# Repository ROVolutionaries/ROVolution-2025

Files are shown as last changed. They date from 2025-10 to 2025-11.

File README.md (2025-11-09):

# ROVolution 2025 Open-Sourced Resources

## **Table of Contents**

* [Hardware](./Hardware) — PCB designs for the ROV’s Power Distribution and Control Boards, created in KiCad with accompanying schematics, layouts, and 3D models.
* [Software](./Software) — Python and C++ code for ROV control, communication, and image processing, including surface interfaces, Raspberry Pi and Pico firmware, and testing utilities.
* [Model](./Model) — 3D models, renders, and Fusion 360 assemblies of the ROV components
* [Ocean Exploration Video Challenge](./Ocean%20Exploration%20Video%20Challenge) — Object detection and classification of ocean species for the NOAA Ocean Exploration Video Challenge. 

---

## **Contributions and Disclaimers**

This repository represents a portion of the overall ROVolution 2025 project, focusing primarily on **design, software development, and task-specific coding**. It does **not include full ROVolutionaries work**. This repository only highlights the contributions specifically carried out by the following members:

* **Konstantin Logashenko (CEO)** — PCB design and software.
* **Dewei David Zhang (CTO)** — CAD design and code contributions.
* **Muhammad Ahmed Shaikh (former CEO)** — software and code contributions.

---

## **More on ROVolution**

* [YouTube](https://www.youtube.com/@ROVolutionaries)
* [Instagram](https://www.instagram.com/rovolutionaries/)
* [Technical Documentation](https://drive.google.com/file/d/1zGqDDCye5YSRfjU_IAGbzJyzfevygd78/view?usp=sharing)
* [Additional Files](https://docs.google.com/spreadsheets/d/10eZ-Em9sXnn5XWBDeCyZJDLGmav5vlog2l0rmnmTBGw/edit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)

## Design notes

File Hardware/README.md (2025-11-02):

# Hardware

---

## **Power Distribution Board (PDB)**

Power Distribution Board
*Note: a few XT60 connectors were not attached in this image.*

**Download:**

* [PDB schematic (`.kicad_sch`)](Power_Distribution_Board/PDB.kicad_sch)
* [PDB PCB layout (`.kicad_pcb`)](Power_Distribution_Board/PDB.kicad_pcb)
* [PDB 3D model (`.step`)](Power_Distribution_Board/PDB.step)
* [PDB bill of materials (`.csv`)](Power_Distribution_Board/PDB.csv)
* [PDB XML export (`.xml`)](Power_Distribution_Board/PDB.xml)
* [PDB project file (`.kicad_pro`)](Power_Distribution_Board/PDB.kicad_pro)
* [PDB KiCad backup schematic (`.kicad_sch-bak`)](Power_Distribution_Board/PDB.kicad_sch-bak)
* [PDB KiCad project local file (`.kicad_prl`)](Power_Distribution_Board/PDB.kicad_prl)

---

## **Control Board**

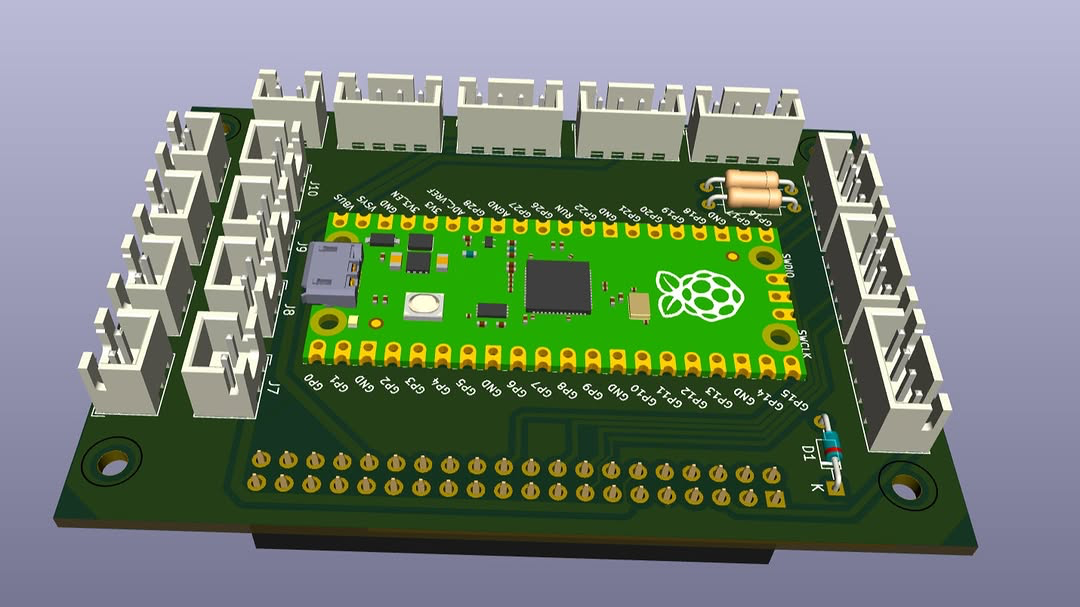
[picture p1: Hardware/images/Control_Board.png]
Control Board


**Download:**

* [Control Board schematic (`.kicad_sch`)](Control_Board/Control_Board.kicad_sch)
* [Control Board PCB layout (`.kicad_pcb`)](Control_Board/Control_Board.kicad_pcb)
* [Control Board 3D model (`.step`)](Control_Board/Control_Board.step)
* [Control Board project file (`.kicad_pro`)](Control_Board/Control_Board.kicad_pro)
* [Control Board KiCad backup schematic (`.kicad_sch-bak`)](Control_Board/Control_Board.kicad_sch-bak)
* [Control Board KiCad project local file (`.kicad_prl`)](Control_Board/Control_Board.kicad_prl)
* [Control Board legacy project file (`.pro`)](Control_Board/Control_Board.pro)

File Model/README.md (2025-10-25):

# Models

---

## **ROV Model**

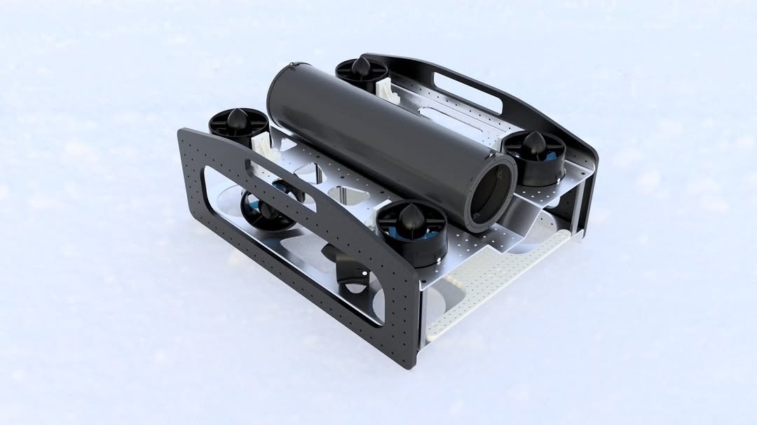
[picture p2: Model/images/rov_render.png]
ROV CAD render

ROV image
[Pool Test Video](https://youtu.be/HalhtXvYYro)

**Download:**  
- [ROV STEP file](files/ROV.step) ([f3z Google Drive file](https://drive.google.com/file/d/1CSuDAXggwamgUQ0F3YDBGZ4MGBTvEjoI/view?usp=sharing))
- [Gripper STEP file](files/Gripper.step) ([f3z Google Drive file](https://drive.google.com/file/d/1I8YvQWp7bbg3L94b0wb-usT_5LE429A_/view?usp=sharing))
- [Photosphere Github download](files/Photosphere.step) ([f3z file](files/Photosphere.f3z))

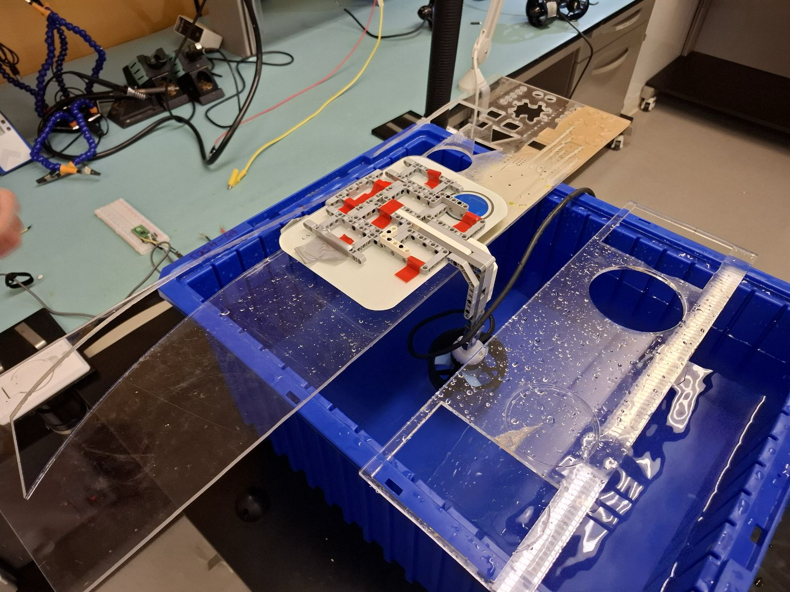
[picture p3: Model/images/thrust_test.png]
Thrust test setup


A custom T200-to-Lego adapter was designed for thrust testing. The STL file can be accessed [here](files/T200_Lego.stl). 

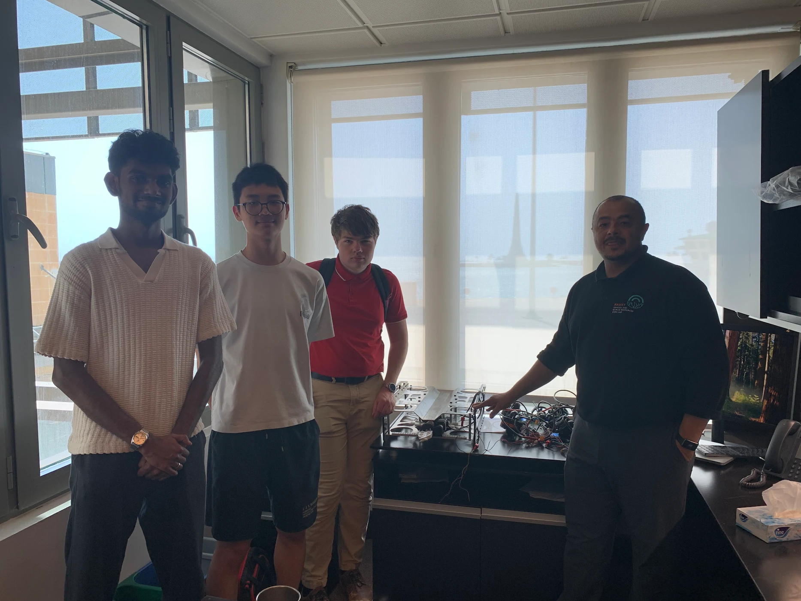
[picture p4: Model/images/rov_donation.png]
ROV donation


After the competition, a representative from the Coastal and Marine Resources Core Lab (CMR), one of our sponsors, was impressed by our design of the ROV. As a gesture of appreciation for CMR’s support, we decided to donate the ROV to CMR for their professional applications.

---

## **Float Model**

Float

**Download:**  

- [Float STEP file](files/Float.step) ([f3z file](files/Float.f3z))

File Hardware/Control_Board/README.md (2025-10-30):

Created in KiCAD 8.0 <br>
Control board of the ROV, follows the Raspberry Pi HAT specification for size, connects to the GPIO pins (does not include EEPROM for identification as per the official spec.
Raspberry Pi is backpowered through the HAT, not ideal however since not all supply protection was included. <br>
All connectors are JST8

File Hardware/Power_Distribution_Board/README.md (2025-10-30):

Project created in KiCAD 8.0
PCB for distributing 12V and 5V power to other component
12 V XT60 Connectors for 8 ESCs, 2 for auxillary components
5V JST8 Connector
Parallel capacitance added on 12 V tether line to balance out tether inductance, reducing voltage spikes due to changes in current drad
TVS diode to protect if transient voltage spikes do occur as described above

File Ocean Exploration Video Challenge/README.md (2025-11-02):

# Program Explanation

**NOAA Ocean Exploration**  
**Ocean Exploration Video Challenge**

---

## **Compute Resources**

Training a visual detection model is computationally intensive, especially when using a dataset of 99k images, as we did. Most laptop and desktop computers will struggle with upwards of 100 images when training on CPUs, and training with one GPU introduces unreasonable training times for large datasets. Therefore, we decided to use a GPU cluster provided by AWS. There, we stored all of our images and trained using job scripts in the SLURM format.  

For prototyping and proof-of-concept purposes, we began by training in Google Colab, but were limited by free GPU credits. Then, we used an AWS cluster with one GPU. Finally, we trained our model using 8 GPUs in the AWS cluster.  

---

## **Code Overview**

We decided to use the model architecture **YOLOv9** with pretrained weights to train our model. Let’s go step by step and learn how to code the model (*please note that most code blocks are snippets and not fully executable scripts*).  

### **Fetching the Data**

This step involves downloading the provided JSON file from **FathomNet**, which contains references to various locations for bounding box annotations, file names, and classes. To maintain consistency, we named each image with its UUID. Below is a snippet of the function we used for this purpose:

```python
def download_image(file):
    filename = file["uuid"]
    url = file["url"]
    image_path = os.path.join(images_directory, filename + ".png")

    if not os.path.exists(image_path):
        try:
            response = requests.get(url, timeout=10)
            if response.status_code == 200:
                with open(image_path, "wb") as img_file:
                    img_file.write(response.content)
                print(f"Image {filename} downloaded successfully.")
                return True
            else:
                print(f"Failed to retrieve the image {filename}. Status code: {response.status_code}")
                return False
        except requests.RequestException as e:
            print(f"Error downloading {filename}: {e}")
            return False
    else:
        print(f"Image {filename} already exists. Skipping download.")
        return False
````

To increase the efficiency of downloading the images, we applied concurrent downloads as shown below:

```python
with ThreadPoolExecutor(max_workers=50) as executor:
    futures = [executor.submit(download_image, file) for file in data]
    for future in as_completed(futures):
        future.result()
```

---

### **Refining the Data**

During the organisation of the files, we refined the dataset to remove any files without crucial information for training purposes and any images or JSON entries that didn’t match or were extra. For example, here is a code snippet to find any extra JSON entries or extra image files:

```python
json_file_path = "data.json"
images_directory = "images/"

with open(json_file_path, "r") as file:
    data = json.load(file)

json_filenames = {entry["uuid"] + ".png" for entry in data}
image_filenames = {filename for filename in os.listdir(images_directory) if filename.endswith(".png")}

extra_json_entries = json_filenames - image_filenames
extra_image_files = image_filenames - json_filenames
```

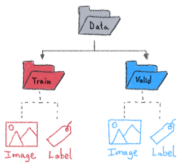
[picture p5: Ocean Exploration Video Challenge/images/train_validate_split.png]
Dataset refinement example


---

### **Organising in YOLO Format**

YOLOv9 requires a very specific data setup for it to function. The basic structure is:
`labels/` and `images/` directories, containing `train/` and `val/` subdirectories (often with an 80/20 split respectively), plus a `data.yaml` file outlining directory paths, number of classes, and class names.

To start, we will use the JSON file of the dataset (in our case FathomNet) to extract the annotations and classes with which we will create our YOLO dataset. Here is a snippet of the function we used to do this:

```python
def extract_json(filename):
    json_file_path = filename
    parser = []

    with open(json_file_path, "r") as file:
        data = json.load(file)  # A

    for file in data:
        filename = os.path.join(file["uuid"] + ".png")
        imgwidth = file["width"]
        imgheight = file["height"]
        for box in file["boundingBoxes"]:
            name = box["concept"]
            boxx = box["x"]
            boxy = box["y"]
            boxwidth = box["width"]
            boxheight = box["height"]  # B
```

Section **A** loads the JSON file given the file path, and section **B** extracts all the necessary data from each JSON entry corresponding to an image.

We used these extracted values to create the `.txt` annotation files in the labels directory, as well as extracting class names later.

To construct the directories, we used the `os` module in Python, specifically `os.makedirs`:

```python
os.makedirs("/ALLFathomNET_images/images/train", exist_ok=True)  # A
os.makedirs("/ALLFathomNET_images/images/val", exist_ok=True)    # A
os.makedirs("/ALLFathomNET_images/labels/train", exist_ok=True)  # A
os.makedirs("/ALLFathomNET_images/labels/val", exist_ok=True)    # A

def save_data(filename, images_folder_path, labels_folder_path, group_obj):
    source = os.path.join("/ALLFathomNET_images/images", filename)
    destination = os.path.join(images_folder_path, filename)
    move(source, destination)
    text_filename = os.path.join(labels_folder_path, os.path.splitext(filename)[0] + ".txt")
    group_obj.get_group(filename).set_index("filename").to_csv(text_filename, sep=' ', index=False, header=False)  # B
```

In the code block above, we created the necessary directories with section **A** and loaded all the annotations and images into their respective directories with section **B**.

Finally, we made our `data.yaml` file containing the key pointers the model needs to access the data:

```python
data = {
    'train': '/ALLFathomNET_images/images/train',
    'val': '/ALLFathomNET_images/images/test',
    'nc': len(labels),
    'names': list(labels.keys())
}

with open('/ALLFathomNET_images/data.yaml', 'w') as file:
    yaml.dump(data, file, default_flow_style=False, sort_keys=False)
```

---

### **Training the Model**

Training with YOLOv9 consists of using the `train.py` function obtained from cloning the repository. In a kernel or terminal, run:

```bash
%cd {HOME}/yolov9  # A
!python train.py \
  --batch 16 --epochs 50 --img 640 --device 0 --min-items 0 --close-mosaic 15 \  # B
  --data /ALLFathomNET_images/data.yaml \  # C
  --weights {HOME}/weights/gelan-c.pt \    # D
  --cfg models/detect/gelan-c.yaml \       # E
  --hyp hyp.scratch-high.yaml
```

Section **A** navigates to the `yolov9` directory cloned from GitHub. Section **B** sets basic parameters for model training. Setting `device=0` means training on one GPU. Sections **C**, **D**, and **E** provide paths to the `data.yaml` file, weights file, and configuration file respectively.

We used the **gelan-c** variant due to its lower computational demands while maintaining strong performance.

---

### **Viewing the Results**

Once training is complete, a `results.png` file will appear showing key model performance metrics (loss and precision).

* **Loss** quantifies the disparity between predictions and true labels.
* **Precision** = True Positives / (True Positives + False Positives).

To view results:

```python
from IPython.display import Image
Image(filename=f"{HOME}/yolov9/runs/train/exp/results.png", width=1000)
```

You can also plot training progress directly using the `results.csv` file:

```python
import pandas as pd
import matplotlib.pyplot as plt

csv_files = [
    'path/to/results1.csv',
    'path/to/results2.csv',
    'path/to/results3.csv'  # A
]

combined_df = pd.DataFrame()
epoch_counter = 0

for csv_file in csv_files:
    df = pd.read_csv(csv_file)  # B
    df.index += epoch_counter
    combined_df = pd.concat([combined_df, df], ignore_index=True)
    epoch_counter += len(df)

plt.figure(figsize=(8, 6))  # C
plt.plot(combined_df.index, combined_df['train/box_loss'], label='Train Box Loss', color='blue')
plt.title('Train Box Loss Over Epochs')
plt.xlabel('Epoch')
plt.ylabel('Loss')
plt.legend()
plt.grid(True)
plt.show()
```

Section **A** defines paths to CSV files, **B** concatenates them, and **C** plots one of the metrics. There are 13 in total.

---

## **User Guide**

The YOLOv9 GitHub repository includes a Python file for running model inference.

To use the model for object detection in a video:

1. Download our trained model weights.
2. Clone the [YOLOv9 GitHub repository](https://github.com/WongKinYiu/yolov9).
3. Use a terminal window and navigate to that directory.
4. Run the following commands:

```bash
pip install -r requirements.txt
python detect.py --source /path/to/video.mp4 --weights '/path/to/weights.pt'
```

The output will indicate the directory where the processed video is saved.

---

## **Model Metrics**

Training metrics can be broadly split into **precision** and **loss**. Over time, performance plateaus even though training continues. By observing these graphs, we can identify when to stop training.

If training metrics improve while validation metrics plateau, the model is **overfitting**.

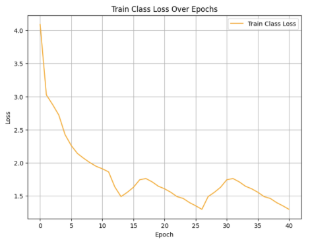
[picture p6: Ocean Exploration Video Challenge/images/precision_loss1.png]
Precision and Loss Plot 1

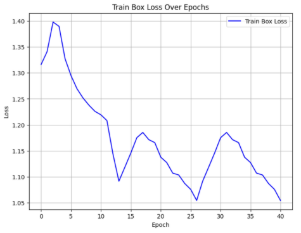
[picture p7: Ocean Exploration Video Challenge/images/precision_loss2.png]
Precision and Loss Plot 2


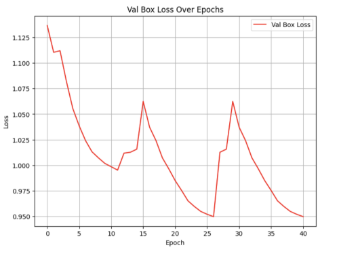
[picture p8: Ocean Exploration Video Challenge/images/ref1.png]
ref1

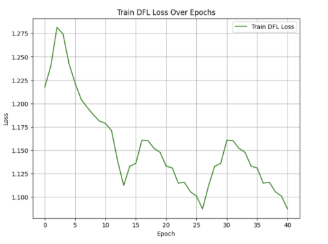
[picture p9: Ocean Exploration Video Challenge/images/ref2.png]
ref2


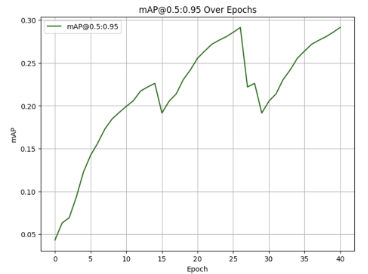
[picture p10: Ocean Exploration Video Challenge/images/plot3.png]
Plot 3

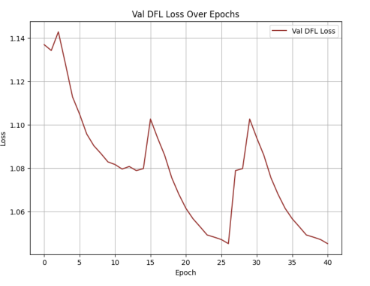
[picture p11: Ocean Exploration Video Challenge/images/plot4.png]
Plot 4

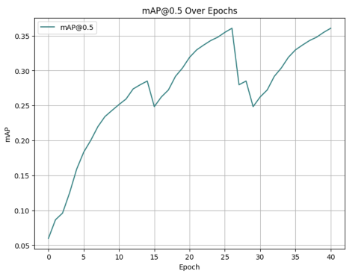
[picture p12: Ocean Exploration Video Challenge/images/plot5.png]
Plot 5

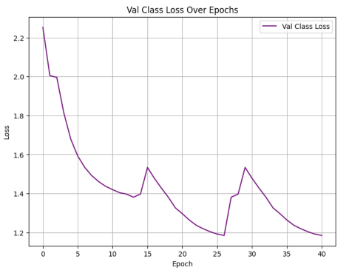
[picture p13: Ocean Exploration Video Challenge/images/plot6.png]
Plot 6


We can see that both the precision and loss metrics have plateaued, indicating that further training would show little improvement. However, large spikes in the middle of training suggest that an incorrect weights file may have been transferred between sessions, reducing model accuracy.

[ref1]: images/ref1.png
[ref2]: images/ref2.png

---

## Model Availability and Credits

Our final trained **YOLOv9 model** is publicly available under an open-source license for research and educational use.

**Download:**  
[Trained model weights (.pt)](https://huggingface.co/petabytecat/rovolutionaries-object-detection/tree/main)  

This project was developed as part of the **NOAA Ocean Exploration Video Challenge** by the **ROVolutionaries**.  

We gratefully acknowledge:

- **NOAA Ocean Exploration** for providing the FathomNet dataset.  
- **Wong Kin Yiu** for open-sourcing the YOLOv9 model.  
- **AWS Cloud Credits for Research** for computational resources.  
- **Aspose** for Converting Word file to Markdown.

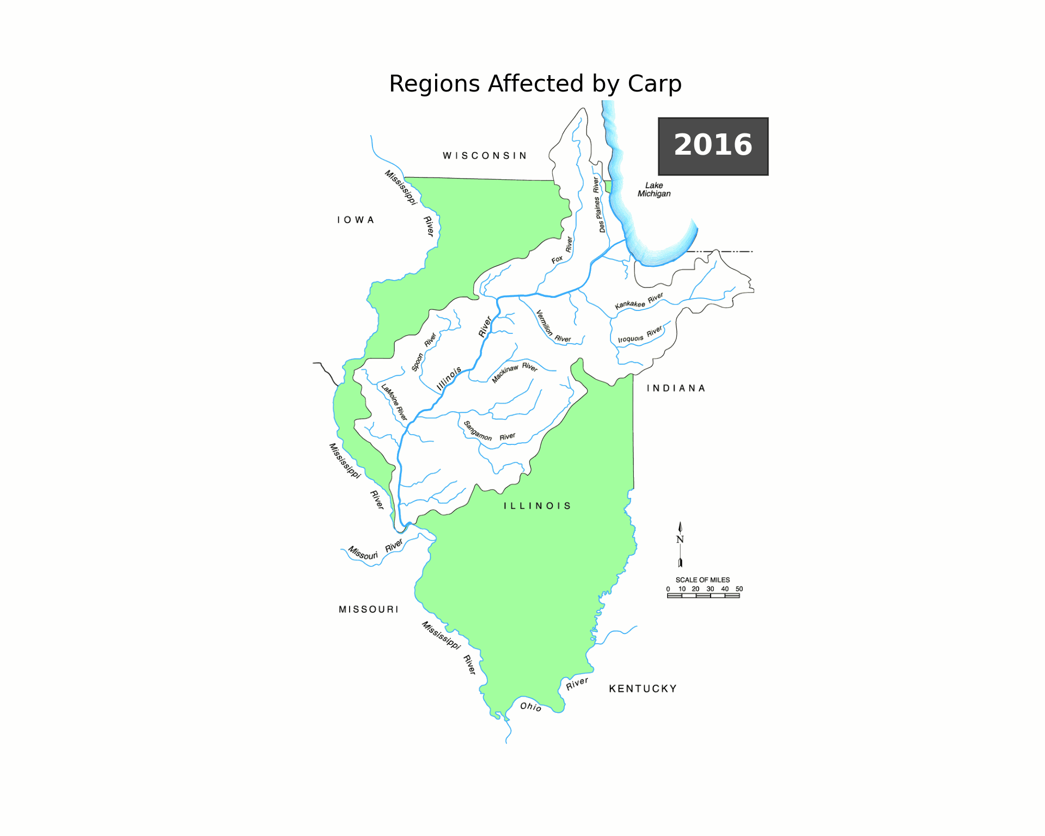
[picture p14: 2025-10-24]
Software/invasive-carp/carp_spread.gif

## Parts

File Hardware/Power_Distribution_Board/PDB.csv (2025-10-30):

Source: | /home/konstantin/rov/ROV_power_board/ROV.kicad_sch
Date: | Tue 07 Jan 2025 01:55:14 PM +03
Tool: | Eeschema 6.0.8+dfsg-1~bpo11+1+rpt1
Generator: | /usr/share/kicad/plugins/bom_csv_grouped_by_value.py
Component Count: | 23
Individual Components:
Item | Qty | Reference(s) | Value | LibPart | Footprint | Datasheet
 |  | C1 | 470 uF | Device:C | Capacitor_THT:CP_Radial_D10.0mm_P3.50mm | ~
 |  | C2 | 470 uF | Device:C | Capacitor_THT:CP_Radial_D10.0mm_P3.50mm | ~
 |  | C3 | 470 uF | Device:C | Capacitor_THT:CP_Radial_D10.0mm_P3.50mm | ~
 |  | C4 | 470 uF | Device:C | Capacitor_THT:CP_Radial_D10.0mm_P3.50mm | ~
 |  | C5 | 470 uF | Device:C | Capacitor_THT:CP_Radial_D10.0mm_P3.50mm | ~
 |  | D1 | P6KEA16A | Device:D_TVS | Diode_THT:D_DO-15_P12.70mm_Horizontal | ~
 |  | H1 | MountingHole | Mechanical:MountingHole | MountingHole:MountingHole_4.3mm_M4 | ~
 |  | H2 | MountingHole | Mechanical:MountingHole | MountingHole:MountingHole_4.3mm_M4 | ~
 |  | H3 | MountingHole | Mechanical:MountingHole | MountingHole:MountingHole_4.3mm_M4 | ~
 |  | H4 | MountingHole | Mechanical:MountingHole | MountingHole:MountingHole_4.3mm_M4 | ~
 |  | IC1 | DCDC_Module_LM2596 | ROV_Parts_Custom:DCDC_Module_LM2596 | ROV_Custom_Footprints:DCDC_Module_2596
 |  | J1 | Tether Anderson Powerpole | Connector_Generic:Conn_01x02 | TerminalBlock:TerminalBlock_bornier-2_P5.08mm | ~
 |  | J2 | ESC TX30 | Connector_Generic:Conn_01x02 | Connector_AMASS:AMASS_XT30U-M_1x02_P5.0mm_Vertical | ~
 |  | J3 | ESC TX30 | Connector_Generic:Conn_01x02 | Connector_AMASS:AMASS_XT30U-M_1x02_P5.0mm_Vertical | ~
 |  | J4 | ESC TX30 | Connector_Generic:Conn_01x02 | Connector_AMASS:AMASS_XT30U-M_1x02_P5.0mm_Vertical | ~
 |  | J5 | ESC TX30 | Connector_Generic:Conn_01x02 | Connector_AMASS:AMASS_XT30U-M_1x02_P5.0mm_Vertical | ~
 |  | J6 | ESC TX30 | Connector_Generic:Conn_01x02 | Connector_AMASS:AMASS_XT30U-M_1x02_P5.0mm_Vertical | ~
 |  | J7 | ESC TX30 | Connector_Generic:Conn_01x02 | Connector_AMASS:AMASS_XT30U-M_1x02_P5.0mm_Vertical | ~
 |  | J8 | ESC TX30 | Connector_Generic:Conn_01x02 | Connector_AMASS:AMASS_XT30U-M_1x02_P5.0mm_Vertical | ~
 |  | J9 | ESC TX30 | Connector_Generic:Conn_01x02 | Connector_AMASS:AMASS_XT30U-M_1x02_P5.0mm_Vertical | ~
 |  | J10 | Aux TX30 | Connector_Generic:Conn_01x02 | Connector_AMASS:AMASS_XT30U-M_1x02_P5.0mm_Vertical | ~
 |  | J11 | Aux TX30 | Connector_Generic:Conn_01x02 | Connector_AMASS:AMASS_XT30U-M_1x02_P5.0mm_Vertical | ~
 |  | J12 | JST8 | Connector_Generic:Conn_01x02 | Connector_JST:JST_XH_S2B-XH-A_1x02_P2.50mm_Horizontal | ~
Collated Components:
Item | Qty | Reference(s) | Value | LibPart | Footprint | Datasheet
1 | 5 | C1, C2, C3, C4, C5 | 470 uF | Device:C | Capacitor_THT:CP_Radial_D10.0mm_P3.50mm | ~
2 | 1 | D1 | P6KEA16A | Device:D_TVS | Diode_THT:D_DO-15_P12.70mm_Horizontal | ~
3 | 4 | H1, H2, H3, H4 | MountingHole | Mechanical:MountingHole | MountingHole:MountingHole_4.3mm_M4 | ~
4 | 1 | IC1 | DCDC_Module_LM2596 | ROV_Parts_Custom:DCDC_Module_LM2596 | ROV_Custom_Footprints:DCDC_Module_2596
5 | 1 | J1 | Tether Anderson Powerpole | Connector_Generic:Conn_01x02 | TerminalBlock:TerminalBlock_bornier-2_P5.08mm | ~
6 | 8 | J2, J3, J4, J5, J6, J7, J8, J9 | ESC TX30 | Connector_Generic:Conn_01x02 | Connector_AMASS:AMASS_XT30U-M_1x02_P5.0mm_Vertical | ~
7 | 2 | J10, J11 | Aux TX30 | Connector_Generic:Conn_01x02 | Connector_AMASS:AMASS_XT30U-M_1x02_P5.0mm_Vertical | ~
8 | 1 | J12 | JST8 | Connector_Generic:Conn_01x02 | Connector_JST:JST_XH_S2B-XH-A_1x02_P2.50mm_Horizontal | ~

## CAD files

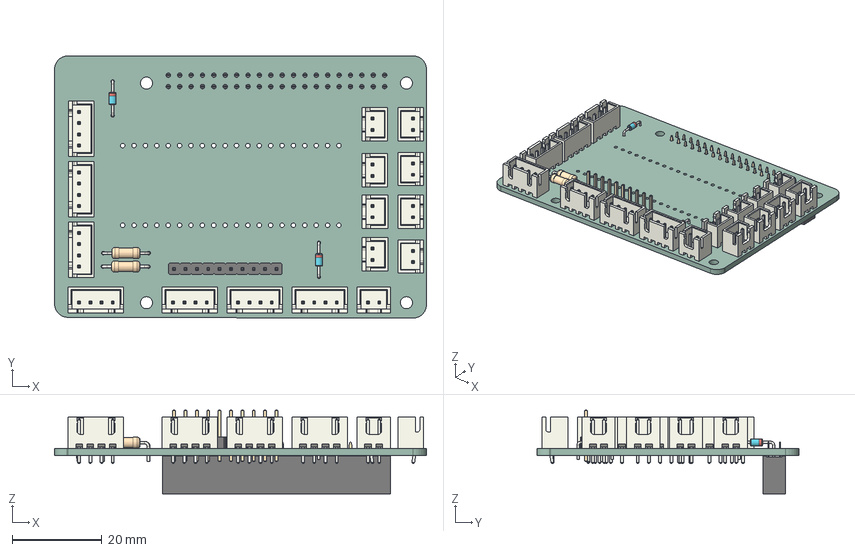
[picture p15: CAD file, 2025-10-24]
Hardware/Control_Board/Control_Board.step
83.0 x 58.5 x 18.7 mm
JST_B4B_XH_A x 7
JST_B2B_XH_A x 9
D_DO-34_SOD68_P7.62mm_Horizontal x 2
R_Axial_DIN0207_L63mm_D25mm_P1016mm_Horizontal x 2
PinHeader_1x10_P254mm_Vertical
PinSocket_2x20_P2.54mm_Vertical
pihat_PCB

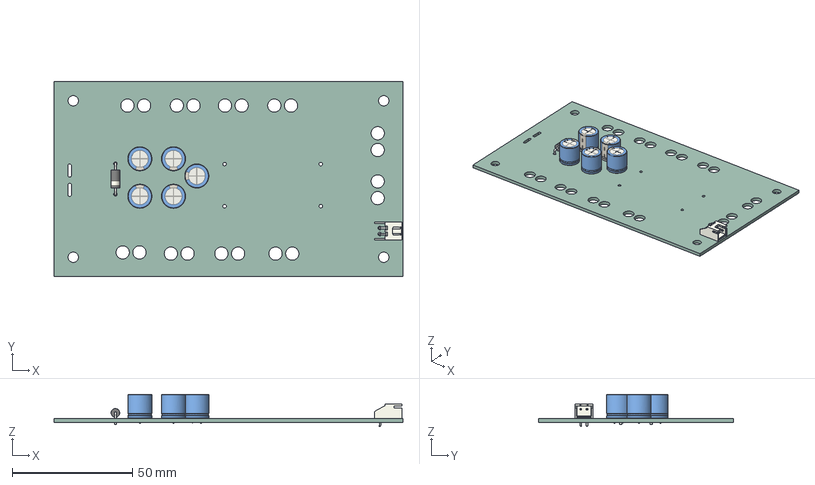
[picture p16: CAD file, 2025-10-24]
Hardware/Power_Distribution_Board/PDB.step
145.0 x 81.0 x 13.4 mm
CP_Radial_D100mm_P350mm x 5
D_DO-15_P12.70mm_Horizontal
JST_S2B_XH_A
_autosave-ROV_PCB

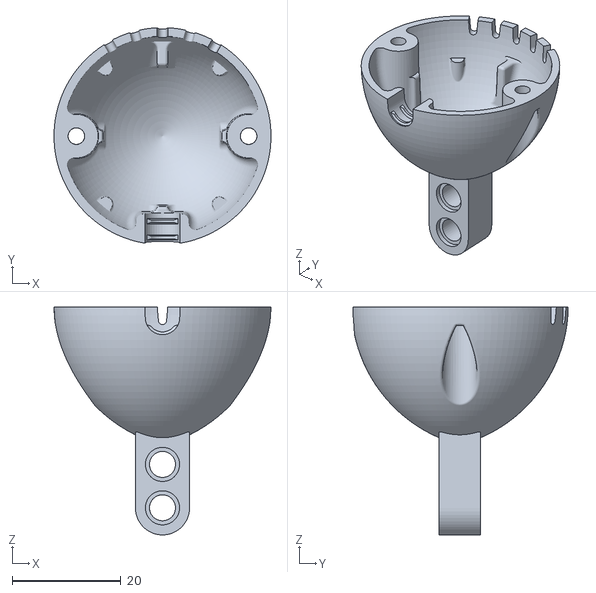
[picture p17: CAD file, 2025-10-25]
Model/files/T200_Lego.stl
40.0 x 39.7 x 42.0

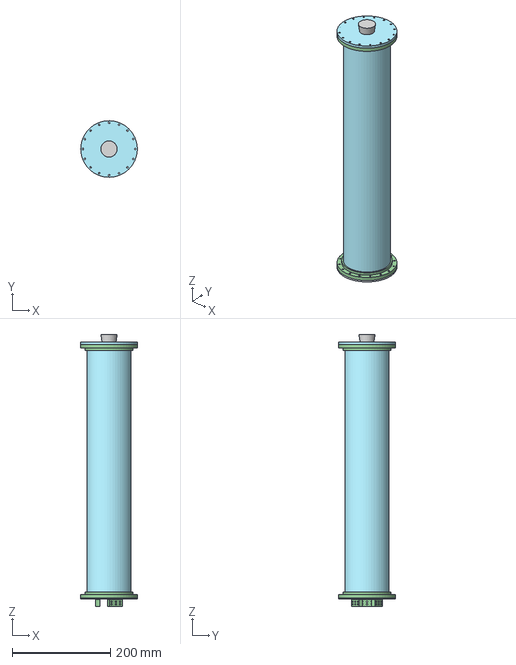
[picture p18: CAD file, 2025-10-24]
Model/files/Float.step
114.9 x 114.9 x 552.8 mm

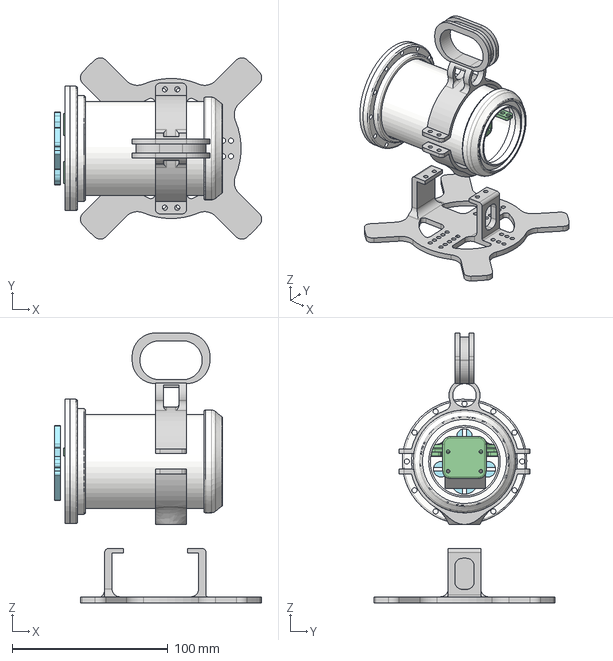
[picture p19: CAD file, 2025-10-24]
Model/files/Photosphere.step
133.2 x 116.5 x 173.4 mm

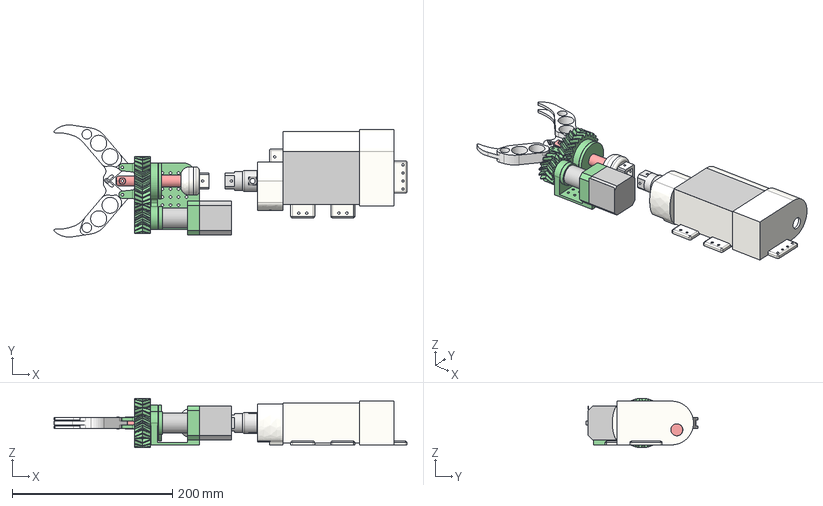
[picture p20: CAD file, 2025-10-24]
Model/files/Gripper.step
440.3 x 139.8 x 61.7 mm
predicted linear actuator v15
linear act container main
linear act container axle
linear act container axle 2
linear act container waterproofer
bearing holder
gripper 2
gripper 1
Stepper_Motor_Gripper
Healical Gear (25R@30.00 m=2.0)
Healical Gear (15R@30.00 m=2.0)
coupler gripper

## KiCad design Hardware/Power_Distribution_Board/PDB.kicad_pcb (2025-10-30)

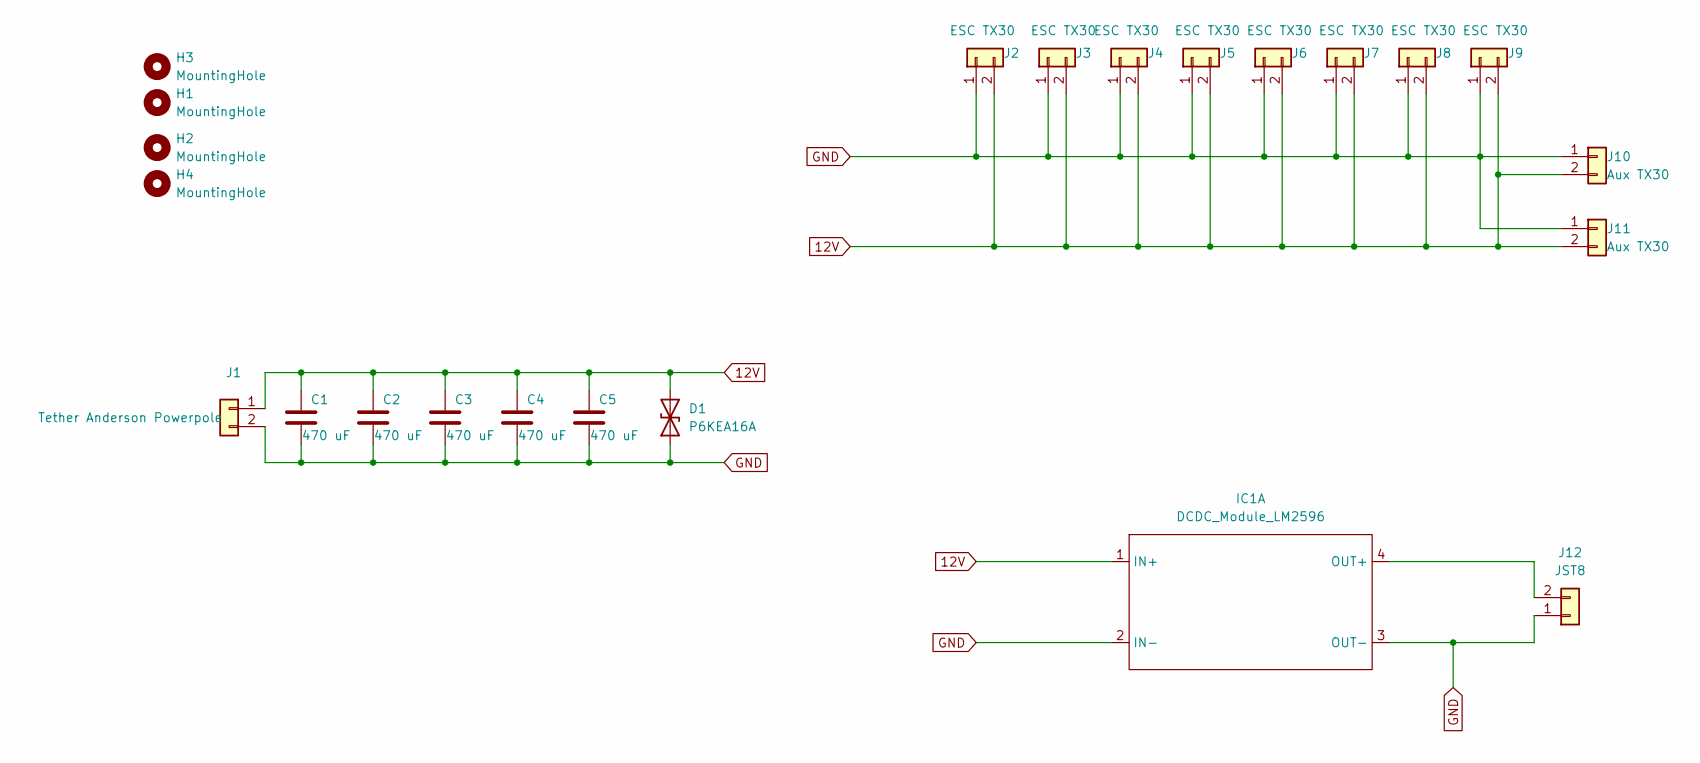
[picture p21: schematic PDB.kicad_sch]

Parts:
C1, C2, C3, C4, C5: 470 uF; CP_Radial_D10.0mm_P3.50mm
D1: P6KEA16A; D_DO-15_P12.70mm_Horizontal
H1, H2, H3, H4: MountingHole; MountingHole_4.3mm_M4
IC1: DCDC_Module_LM2596; DCDC_Module_2596
J1: Tether Anderson Powerpole; TerminalBlock_bornier-2_P5.08mm
J2, J3, J4, J5, J6, J7, J8, J9: ESC TX30; AMASS_XT30U-M_1x02_P5.0mm_Vertical
J10, J11: Aux TX30; AMASS_XT30U-M_1x02_P5.0mm_Vertical
J12: JST8; JST_XH_S2B-XH-A_1x02_P2.50mm_Horizontal

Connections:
12V: C1.1, C2.1, C3.1, C4.1, C5.1, D1.2 (A2), IC1.1 (IN+), J1.1, J2.2, J3.2, J4.2, J5.2, J6.2, J7.2, J8.2, J9.2, J10.2, J11.2
GND: C1.2, C2.2, C3.2, C4.2, C5.2, D1.1 (A1), IC1.2 (IN-), IC1.3 (OUT-), J1.2, J2.1, J3.1, J4.1, J5.1, J6.1, J7.1, J8.1, J9.1, J10.1, J11.1, J12.1
unnamed: IC1.4 (OUT+), J12.2

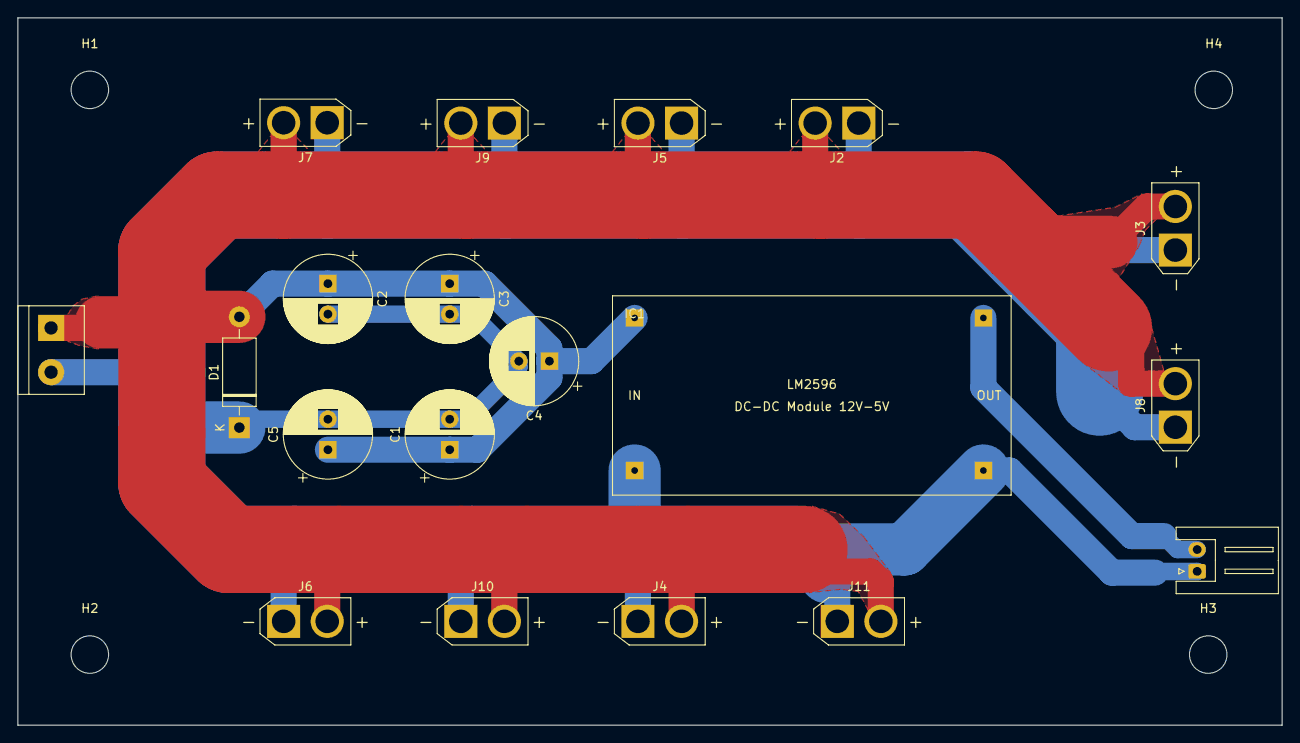
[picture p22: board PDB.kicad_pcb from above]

Board: 2 copper layers, 145.0 x 81.1 mm, 23 parts (0 on the bottom side), 3 nets.

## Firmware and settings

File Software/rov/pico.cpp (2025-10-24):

#include "pico/stdlib.h"
#include <stdio.h>
#include "hardware/adc.h"
#include "hardware/pwm.h"
#include "hardware/uart.h"
#include <array>
#include "hardware/i2c.h"
#include "pico/binary_info.h"


#define UART_ID uart1
#define UART_TX_PIN 8
#define UART_RX_PIN 9


//UART handler data
static uint8_t byte_count = 0;
static uint8_t signal = 0;
static uint8_t thrust_gain = 0;
char data[2];


static const uint BAUDRATE = 115200; // 100 kHz
static int addr = 0x68;


//PWM microsecond values for forward, stop, reverse
const uint16_t F = 1900;
const uint16_t S = 1500;
const uint16_t R = 1100;

// LED PIN
const uint LED_PIN = PICO_DEFAULT_LED_PIN;

float thrust;

// Thrusters
const uint8_t vMotor1 = 1;
const uint8_t vMotor2 = 2;
const uint8_t vMotor3 = 3;
const uint8_t vMotor4 = 10;
const uint8_t hMotor1 = 11;
const uint8_t hMotor2 = 6;
const uint8_t hMotor3 = 7;
const uint8_t hMotor4 = 0;

std::array<uint8_t, 8> motor_pins = {vMotor1, vMotor2, vMotor3, vMotor4, hMotor1, hMotor2, hMotor3, hMotor4};

// Sensors
const uint8_t pH_pin = 28;  // ADC input on GPIO 28
const uint8_t leak_pin = 16;

bool isLeak = false;

std::array<uint, 8> slice_num;
std::array<uint, 8> channel;

//IMU Values
int16_t acceleration[3], gyro[3], temp;


// Initialise all thrusters to pulse width 1500 microseconds
void initialize_motors() {
    uint8_t motors[] = {vMotor1, vMotor2, vMotor3, vMotor4, hMotor1, hMotor2, hMotor3, hMotor4};

    for (int i = 0; i < 8; i++) {
        gpio_set_function(motors[i], GPIO_FUNC_PWM);
        slice_num[i] = pwm_gpio_to_slice_num(motors[i]);
        channel[i] = pwm_gpio_to_channel(motors[i]);
        pwm_set_clkdiv_int_frac (slice_num[i],  9,9);
        pwm_set_wrap(slice_num[i], 65465);
        pwm_set_chan_level(slice_num[i], channel[i], 19639.5);
        pwm_set_enabled(slice_num[i], true);
    }
    sleep_ms(3000);
}

void set_pw(uint8_t pin, uint16_t duty_us) {
    uint16_t level =(uint16_t)(65465 * ((float)duty_us/5000));
    pwm_set_chan_level(pwm_gpio_to_slice_num(pin), pwm_gpio_to_channel(pin), level);
}

// Basic motor functions
void forward(uint8_t motor, uint8_t thrust) {
    set_pw(motor, 1500 + thrust * 400);
}

void reverse(uint8_t motor, uint8_t thrust) {
    set_pw(motor, 1500 + thrust * 400);
}

void stop(uint8_t motor) {
    set_pw(motor, 1500);
}

// Vectored movement functions
void move_forward(uint8_t thrust) {
    forward(hMotor3, thrust);
    forward(hMotor4, thrust);
    reverse(hMotor1, thrust);
    reverse(hMotor2, thrust);
}

void back(uint8_t thrust) {
    reverse(hMotor3, thrust);
    reverse(hMotor4, thrust);
    forward(hMotor1, thrust);
    forward(hMotor2, thrust);
}

void right(uint8_t thrust) {
    forward(hMotor1, thrust);
    forward(hMotor3, thrust);
    reverse(hMotor2, thrust);
    reverse(hMotor4, thrust);
}

void left(uint8_t thrust) {
    forward(hMotor2, thrust);
    forward(hMotor4, thrust);
    reverse(hMotor1, thrust);
    reverse(hMotor3, thrust);
}

void forward_left(uint8_t thrust) {
    forward(hMotor4, thrust);
    reverse(hMotor1, thrust);
}

void forward_right(uint8_t thrust) {
    forward(hMotor3, thrust);
    reverse(hMotor2, thrust);
}

void back_left(uint8_t thrust) {
    forward(hMotor1, thrust);
    reverse(hMotor4, thrust);
}

void back_right(uint8_t thrust) {
    reverse(hMotor3, thrust);
    forward(hMotor2, thrust);
}

void up(uint8_t thrust) {
    reverse(vMotor1, thrust);
    reverse(vMotor2, thrust);
    reverse(vMotor3, thrust);
    reverse(vMotor4, thrust);
}

void down(uint8_t thrust) {
    forward(vMotor1, thrust);
    forward(vMotor2, thrust);
    forward(vMotor3, thrust);
    forward(vMotor4, thrust);
}

void roll_right(uint8_t thrust) {
    forward(vMotor1, thrust);
    reverse(vMotor2, thrust);
    forward(vMotor3, thrust);
    reverse(vMotor4, thrust);
}

void roll_left(uint8_t thrust) {
    reverse(vMotor1, thrust);
    forward(vMotor2, thrust);
    reverse(vMotor3, thrust);
    forward(vMotor4, thrust);
}

void pitch_forward(uint8_t thrust) {
    forward(vMotor1, thrust);
    forward(vMotor2, thrust);
    reverse(vMotor3, thrust);
    reverse(vMotor4, thrust);
}

void pitch_back(uint8_t thrust) {
    reverse(vMotor1, thrust);
    reverse(vMotor2, thrust);
    forward(vMotor3, thrust);
    forward(vMotor4, thrust);
}

void yaw_right(uint8_t thrust) {
    reverse(hMotor3, thrust);
    forward(hMotor4, thrust);
    forward(hMotor1, thrust);
    reverse(hMotor2, thrust);
}

void yaw_left(uint8_t thrust) {
    forward(hMotor3, thrust);
    reverse(hMotor4, thrust);
    reverse(hMotor1, thrust);
    forward(hMotor2, thrust);
}

uint16_t read_ph() {
    adc_select_input(2);  // Select ADC input 2 (GPIO 28)
    uint16_t raw_pH = adc_read();
    // Update later to include some operation to convert to reading between 0 and 14
    return raw_pH;
}

bool check_leak() {
    isLeak = !gpio_get(leak_pin);  // Invert because 0 means leak detected
    return isLeak;
}

static void mpu6050_reset() {
    // Two byte reset. First byte register, second byte data
    // There are a load more options to set up the device in different ways that could be added here
    uint8_t buf[] = {0x6B, 0x80};
    i2c_write_blocking(i2c_default, addr, buf, 2, false);
    sleep_ms(100); // Allow device to reset and stabilize

    // Clear sleep mode (0x6B register, 0x00 value)
    buf[1] = 0x00;  // Clear sleep mode by writing 0x00 to the 0x6B register
    i2c_write_blocking(i2c_default, addr, buf, 2, false); 
    sleep_ms(10); // Allow stabilization after waking up
}

static void mpu6050_read_raw(int16_t accel[3], int16_t gyro[3], int16_t *temp) {
    // For this particular device, we send the device the register we want to read
    // first, then subsequently read from the device. The register is auto incrementing
    // so we don't need to keep sending the register we want, just the first.

    uint8_t buffer[6];

    // Start reading acceleration registers from register 0x3B for 6 bytes
    uint8_t val = 0x3B;
    i2c_write_blocking(i2c_default, addr, &val, 1, true); // true to keep master control of bus
    i2c_read_blocking(i2c_default, addr, buffer, 6, false);

    for (int i = 0; i < 3; i++) {
        accel[i] = (buffer[i * 2] << 8 | buffer[(i * 2) + 1]);
    }

    // Now gyro data from reg 0x43 for 6 bytes
    // The register is auto incrementing on each read
    val = 0x43;
    i2c_write_blocking(i2c_default, addr, &val, 1, true);
    i2c_read_blocking(i2c_default, addr, buffer, 6, false);  // False - finished with bus

    for (int i = 0; i < 3; i++) {
        gyro[i] = (buffer[i * 2] << 8 | buffer[(i * 2) + 1]);;
    }

    // Now temperature from reg 0x41 for 2 bytes
    // The register is auto incrementing on each read
    val = 0x41;
    i2c_write_blocking(i2c_default, addr, &val, 1, true);
    i2c_read_blocking(i2c_default, addr, buffer, 2, false);  // False - finished with bus

    *temp = buffer[0] << 8 | buffer[1];
}


void on_uart_rx() {
    gpio_put(LED_PIN, 0);
    while (uart_is_readable(UART_ID)){
        uint8_t ch = uart_getc(UART_ID);
        printf("Received byte: %d\n", ch);

        if (ch >= 0 && ch <= 17){
            //signal = int_from_uart(UART_ID);
            signal = ch;
            printf("Signal: %d\n", signal);
            //byte_count++;
        }
        if(ch >= 18 && ch <= 118){
            //thrust_gain = int_from_uart(UART_ID) - 18;
            thrust_gain = ch - 18;
            printf("Thrust: %d\n", thrust_gain);
            //byte_count = 0;
        }

        float thrust = thrust_gain / 100.0f;  // Convert back to 0.0-1.0 range

        switch(signal) {
            case 0: gpio_put(LED_PIN, 1); break;
            case 1: move_forward(thrust); break;
            case 2: back(thrust); break;
            case 3: right(thrust); break;
            case 4: left(thrust); break;
            case 5: forward_left(thrust); break;
            case 6: forward_right(thrust); break;
            case 7: back_left(thrust); break;
            case 8: back_right(thrust); break;
            case 9: up(thrust); break;
            case 10: down(thrust); break;
            case 11: roll_right(thrust); break;
            case 12: roll_left(thrust); break;
            case 13: pitch_forward(thrust); break;
            case 14: pitch_back(thrust); break;
            case 15: yaw_right(thrust); break;
            case 16: yaw_left(thrust); break;
            case 17: printf("pH Raw Value: %d\n", read_ph()); break;
            default: break; // Do nothing for unrecognized signals
            //need to add sending sensor data functionality
        }
    }

    
}

void setup_uart() {
    uart_init(UART_ID, BAUDRATE);
    gpio_set_function(UART_TX_PIN, GPIO_FUNC_UART);
    gpio_set_function(UART_RX_PIN, GPIO_FUNC_UART);
    uart_set_hw_flow(UART_ID, false, false);
    uart_set_format(UART_ID, 8, 1, UART_PARITY_NONE);
    uart_set_baudrate(UART_ID, BAUDRATE);
    uart_set_fifo_enabled(UART_ID, false);

    int UART_IRQ = UART_ID == uart0 ? UART0_IRQ : UART1_IRQ;
    irq_set_exclusive_handler(UART_IRQ, on_uart_rx); //UART 0 or 1?
    irq_set_enabled(UART_IRQ, true);
    uart_set_irq_enables(UART_ID, true, false);

}

void setup_i2c() {
    // This example will use I2C0 on the default SDA and SCL pins (4, 5 on a Pico)
    i2c_init(i2c_default, 400 * 1000);
    gpio_set_function(PICO_DEFAULT_I2C_SDA_PIN, GPIO_FUNC_I2C);
    gpio_set_function(PICO_DEFAULT_I2C_SCL_PIN, GPIO_FUNC_I2C);
    gpio_pull_up(PICO_DEFAULT_I2C_SDA_PIN);
    gpio_pull_up(PICO_DEFAULT_I2C_SCL_PIN);
    // Make the I2C pins available to picotool
    bi_decl(bi_2pins_with_func(PICO_DEFAULT_I2C_SDA_PIN, PICO_DEFAULT_I2C_SCL_PIN, GPIO_FUNC_I2C));

    mpu6050_reset();

}

void print_IMU(){
    mpu6050_read_raw(acceleration, gyro, &temp);
    // These are the raw numbers from the chip, so will need tweaking to be really useful.
    // See the datasheet for more information
    printf("Acc. X = %d, Y = %d, Z = %d\n", acceleration[0], acceleration[1], acceleration[2]);
    printf("Gyro. X = %d, Y = %d, Z = %d\n", gyro[0], gyro[1], gyro[2]);
    // Temperature is simple so use the datasheet calculation to get deg C.
    // Note this is chip temperature.
    printf("Temp. = %f\n", (temp / 340.0) + 36.53);

}

int main() {
    stdio_init_all();

    // Initialize ADC for pH sensor
    adc_init();
    adc_gpio_init(pH_pin);

    // Initialize leak sensor pin
    gpio_init(leak_pin);
    gpio_set_dir(leak_pin, GPIO_IN);

    // Initialize LED
    gpio_init(LED_PIN);
    gpio_set_dir(LED_PIN, GPIO_OUT);

    //initialize_motors();
    gpio_put(LED_PIN, 1);

    initialize_motors();
    
    set_pw(1, 1400);

    sleep_ms(5000);

    set_pw(1, 1500);

    gpio_put(LED_PIN, 0);

    setup_uart();
    setup_i2c();

    while(1){
        tight_loop_contents();
    }
    return 0;
}

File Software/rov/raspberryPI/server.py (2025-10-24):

import socket
import time
import struct
import serial
import pigpio
import threading

'''
SIGNALS TO RECEIVE:

0 - ZERO EVERYTHING

#FLOAT DATA TYPE#
1 - Forward
2 - Reverse
3 - Lateral Right
4 - Lateral Left
5 - Forward Left
6 - Forward Right
7 - Back Left
8 - Back Right
9 - Ascend
10 - Descend
11 - Roll Right
12 - Roll Left
13 - Pitch Up
14 - Pitch Down
15 - Yaw Right
16 - Yaw Left

#INT DATA TYPE#
17 - Jelly open/close
18 - Fish open/close
19 - Tilt camera up/down
20 - Grabber open/close
21 - Switch camera previous/next

#BOOLEAN DATA TYPE#
22 - Toggle Precision Mode
23 - Toggle Stabilise Mode
24 - Reset attitude

25 - ZERO EVERYTHING
'''

# pigpio initialisation
pi = pigpio.pi() 
#pin definitions
jelly_servo = 13
fish_servo = 12 
tilt_servo = 19
linear_forward = 24
linear_back = 25
leak_sensor = 26
pi.set_mode(fish_servo, pigpio.OUTPUT)
pi.set_mode(jelly_servo, pigpio.OUTPUT)
pi.set_mode(tilt_servo, pigpio.OUTPUT)
pi.set_mode(linear_forward, pigpio.OUTPUT)
pi.set_mode(linear_back, pigpio.OUTPUT)
pi.set_mode(leak_sensor, pigpio.INPUT)

#data structures for pico communication
header_float = b'\x01'
header_int = b'\x02'
header_boolean = b'\x03'
format_float = "<if"
format_int = "<ii"
format_boolean = "<i?"
pico_signal = []

#data structures for surface communication
isLeak = False
gyro_pos = []

#Serial for reading and writing to Pico
try: 
    ser = serial.Serial('/dev/serial0', 115200, timeout=5)
except:
    print("No UART detected. Please wire UART and try again.")

# Create UDP socket
bufferSize = 1024
serverPort = 2222
sendPort = 5000
# STATIC ADDRESS: serverIP = '192.168.1.100'
serverIP = '169.254.37.82'

server_socket = socket.socket(socket.AF_INET, socket.SOCK_DGRAM)
server_socket.bind((serverIP, serverPort))
print('Server listening...')
# Create a new socket for sending data
send_socket = socket.socket(socket.AF_INET, socket.SOCK_DGRAM)
send_socket.bind((serverIP, sendPort))


print("Waiting for 'Hello' from client...")
while True:
    message, address = server_socket.recvfrom(bufferSize)
    print(f"Received raw message: {message}")
    try:
        if message.decode('utf-8') == "Hello":
            print("Handshake complete with:", address)
            break  # Only now start the threads
    except UnicodeDecodeError:
        # Not a valid Hello, maybe junk
        continue


def control():
    print("Started control loop.")
    while True:
        # Receiving blocking from client. Waits until a message is received.
        message, address = server_socket.recvfrom(bufferSize)

        header = message[0]  # first byte: header (int)
        print("Header: ", header)
        print("Signal: ", message[1])
        print("Data: ", message[2])


        # Now unpack based on header type
        
        if header == 1:  # float
            if len(message[1:]) != 8:
                print(f"Invalid message length: {len(message[1:])} bytes")
                continue
            signal, data = struct.unpack(format_float, message[1:])
            print(f"Received FLOAT: Signal: {signal}, Data: {data}")
        elif header == 2:  # int
            signal, data = struct.unpack(format_int, message[1:])
            print(f"Received INT: Signal: {signal}, Data: {data}")
        elif header == 3:  # boolean
            signal, data = struct.unpack(format_boolean, message[1:])
            print(f"Received BOOLEAN: Signal: {signal}, Data: {data}")
        else:
            print(f"Unknown header: {header}")
            continue

        # Now act on the signal as before
        if signal in range(1, 17):
            thrust = int(data * 100)
            print("Thrust: ", thrust)
            pico_signal = [signal, thrust]
            ser.write(bytes(pico_signal))
        elif signal == 17:
            print("Signal:", signal)
            print("Data:", data)
            pi.set_servo_pulsewidth(jelly_servo, data)
        elif signal == 18:
            print("Signal:", signal)
            print("Data:", data)
            pi.set_servo_pulsewidth(fish_servo, data)
        elif signal == 19:
            print("Signal:", signal)
            print("Data:", data)
            pi.set_servo_pulsewidth(tilt_servo, data)
        elif signal == 20:
            print("Signal:", signal)
            print("Data:", data)
            if data == 1:
                pi.write(linear_forward, 1)
            else:
                pi.write(linear_back, 1)
        elif signal == 21:
            print("Signal:", signal)
            print("Data:", data)
            # Camera switch code - KONSTANTIN
            print()

def telemetry():
    print("Started telemetry loop")
    global gyro_pos, isLeak, addr
    while True:
        if ser.in_waiting > 0:
            gyro_pos = ser.read(24)
            isLeak = pi.read(leak_sensor)
            send_socket.sendto(gyro_pos + isLeak, addr)
        time.sleep(0.1)


t1 = threading.Thread(target=control, args=[])
t2 = threading.Thread(target=telemetry, args=[])
t1.start()
t2.start()

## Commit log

2025-10-24 step file upload
    [Float.step, Gripper.step, Photosphere.step]
2025-10-24 upload pcb
    [Power_Board.step, pihat.step]
2025-10-25 thrust test
    [T200_Lego.stl]
2025-10-30 Directory for Power Board
2025-10-30 Upload KiCAD files for Power Board
    [PDB.csv, PDB.kicad_pcb, PDB.kicad_sch]
2025-10-30 Create directory for Logic PCB
2025-10-30 Upload KiCAD files for control board
    [Control_Board.kicad_pcb, Control_Board.kicad_sch, Control_Board.sch]
2025-11-02 update hardware readme file
    [Control_Board.step, PDB.step, Power_Board.step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]
